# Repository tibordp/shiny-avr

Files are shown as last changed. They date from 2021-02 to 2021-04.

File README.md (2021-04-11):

# Shiny AVR Programmer

USB AVR ISP programmer specifically designed for ATtiny25/45/85 and ATtiny24/44/84/241/441/841 microcontroller families in DIP packages.

Blasphemeously designed with an STM32 microcontroller instead of an another AVR.

Shiny AVR programmer provides an 16 MHz clock signal, which allows programming chips that have had their fuse bits set to require an external crystal or clock signal.

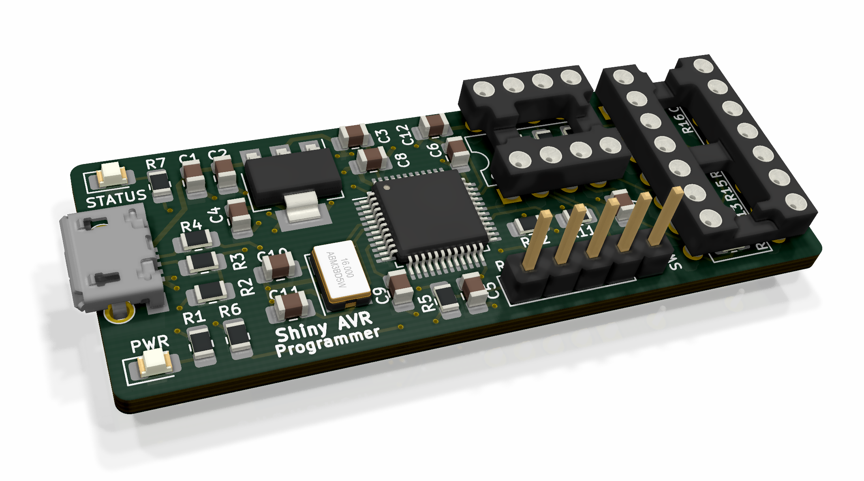
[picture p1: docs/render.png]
render


# Usage

Insert the ATtiny into the DIP socket on the programmer. Please make sure it is oriented the right way. It should also work for programming the ATtinys in circuit (unless there is circuitry wired to it that would interfere, which is likely, since ATtinys don't have dedicated programming pins), but since there is no standard ISP header on the board, you will need to provide an adapter cable.

Shiny AVR powers ATtinys with 3.3V.

## Arduino

Shiny AVR Programmer will present to the host computer as a virtual USB serial port. It can be used seamlessly from Arduino IDE by
selecting **Tools > Programmer > Arduino as ISP** and selecting the appropriate serial port.

## avrdude

Use `-c arduino` command-line parameter.

## PlatformIO

It requires some modifications to use the [avrdude.conf from ATTinyCore](https://github.com/SpenceKonde/ATTinyCore/blob/master/avr/avrdude.conf) instead of the default one bundled with PlatformIO (`chip_erase_delay` is too low in the stock one).

Example config for ATtiny85

```ini
[env:attiny85]
platform = atmelavr
board = attiny85
upload_protocol = custom
upload_flags =
    -C$PROJECT_PACKAGES_DIR/framework-arduino-avr-attiny/avrdude.conf
    -p$BOARD_MCU
    -P$UPLOAD_PORT
    -b$UPLOAD_SPEED
    -carduino
upload_command = avrdude $UPLOAD_FLAGS -U flash:w:$SOURCE:i

upload_port = <your serial port device here>
upload_speed = 19200
board_build.f_cpu = 16000000L
board_fuses.lfuse = 0xD1
board_fuses.hfuse = 0xDF
board_fuses.efuse = 0xFF
```

Example config for ATtiny84

```ini
[env:attiny84]
platform = atmelavr
board = attiny84
upload_protocol = custom
upload_flags =
    -C$PROJECT_PACKAGES_DIR/framework-arduino-avr-attiny/avrdude.conf
    -p$BOARD_MCU
    -P$UPLOAD_PORT
    -b$UPLOAD_SPEED
    -carduino
upload_command = avrdude $UPLOAD_FLAGS -U flash:w:$SOURCE:i

upload_port = <your serial port device here>
upload_speed = 19200
board_build.f_cpu = 8000000L
board_fuses.lfuse = 0x62
board_fuses.hfuse = 0xDF
board_fuses.efuse = 0xFF
```

# Hardware

The schematic and PCB layout are in the [kicad](./kicad) folder.

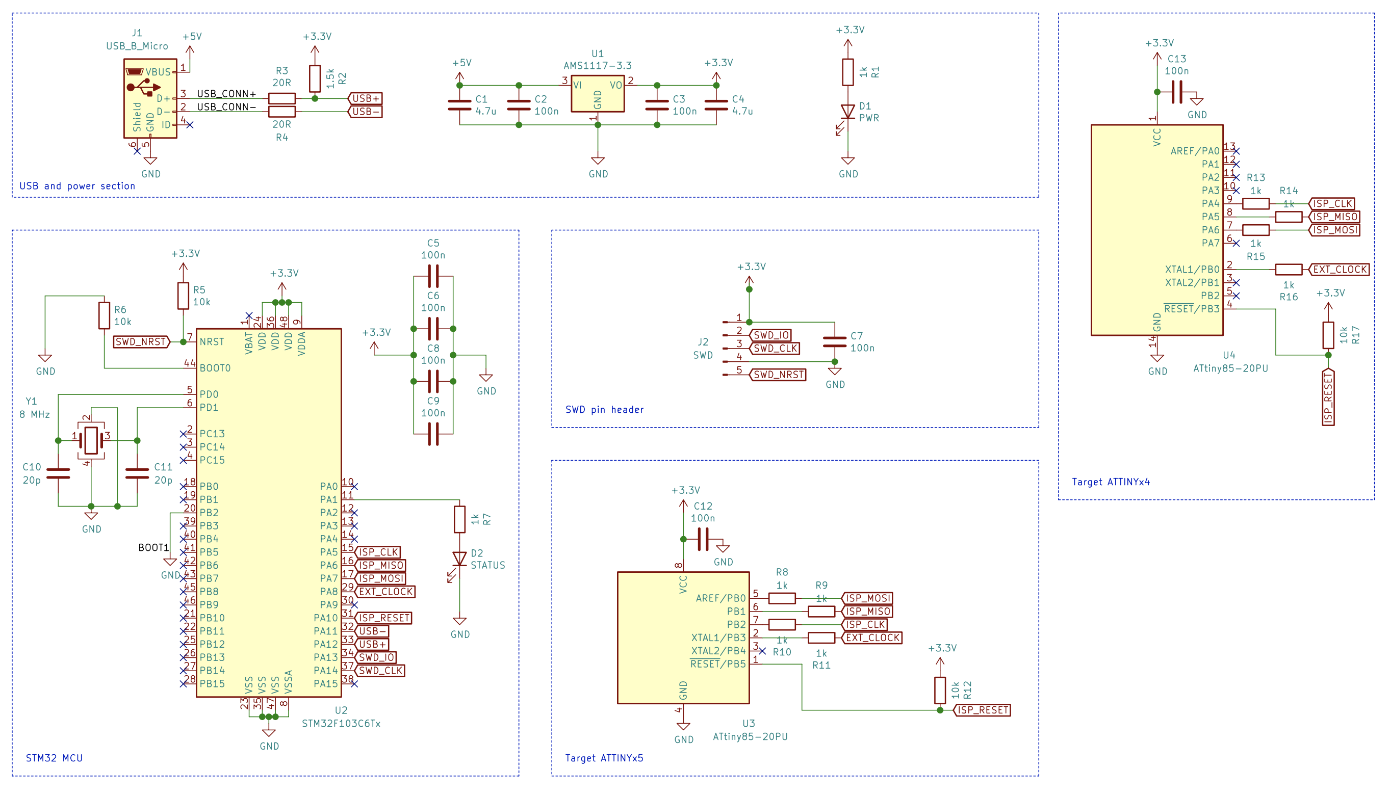
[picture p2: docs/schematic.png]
schematic

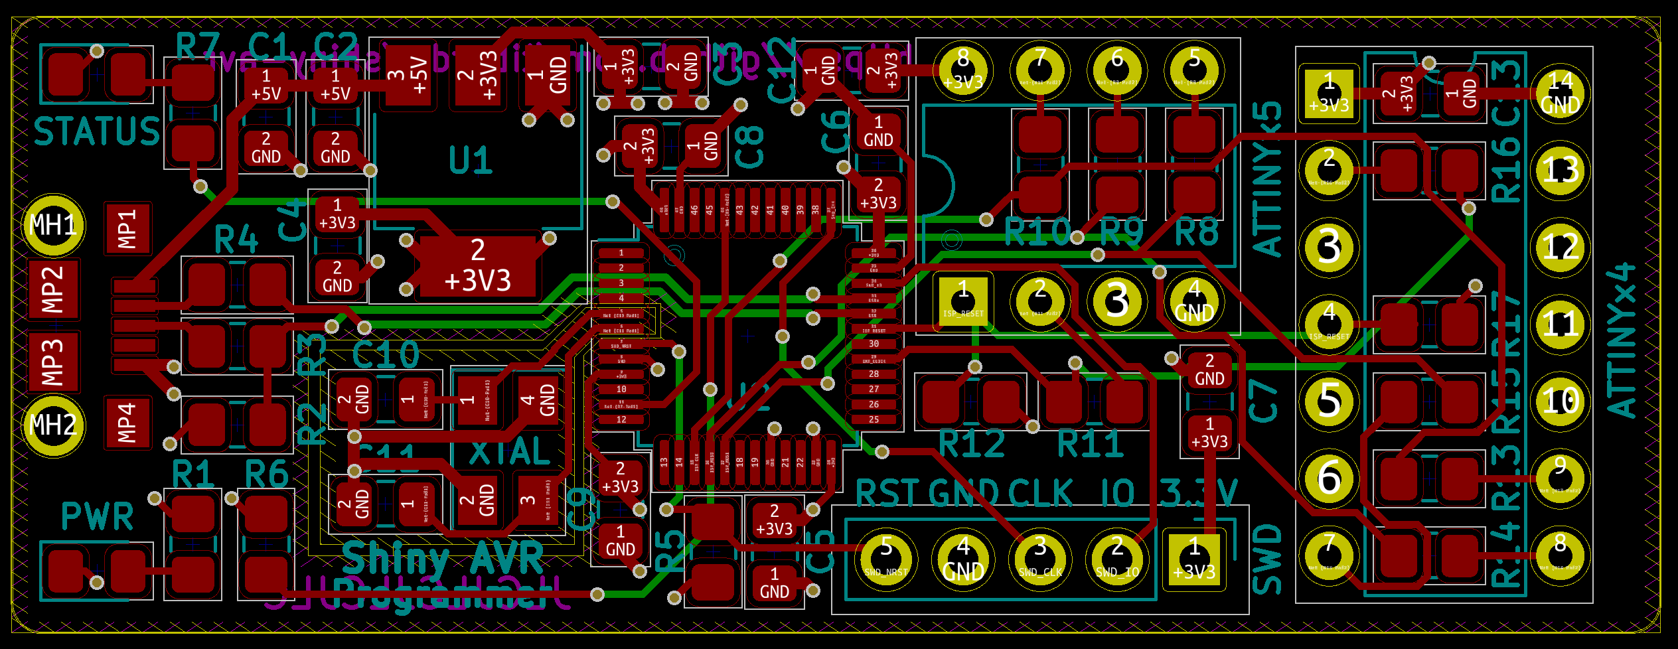
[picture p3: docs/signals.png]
signals


# Firmware

Firmware is based on [ArduinoISP](https://github.com/arduino/arduino-examples/blob/main/examples/11.ArduinoISP/ArduinoISP/ArduinoISP.ino) with the 
appropriate modifications for the specifics of hardware (LEDs, SPI parameters, ...) and it adds the capability to provide external clock to be able
to program ATtinys that have had their fuses set to rely on external clock or crystal.

# Roadmap

- High voltage programming support for chips `RSTDISBL` or debugWIRE fuse bits set  
- Managed power supply or a PTC to prevent damaging the chips 
  that are inserted upside down in the socket.

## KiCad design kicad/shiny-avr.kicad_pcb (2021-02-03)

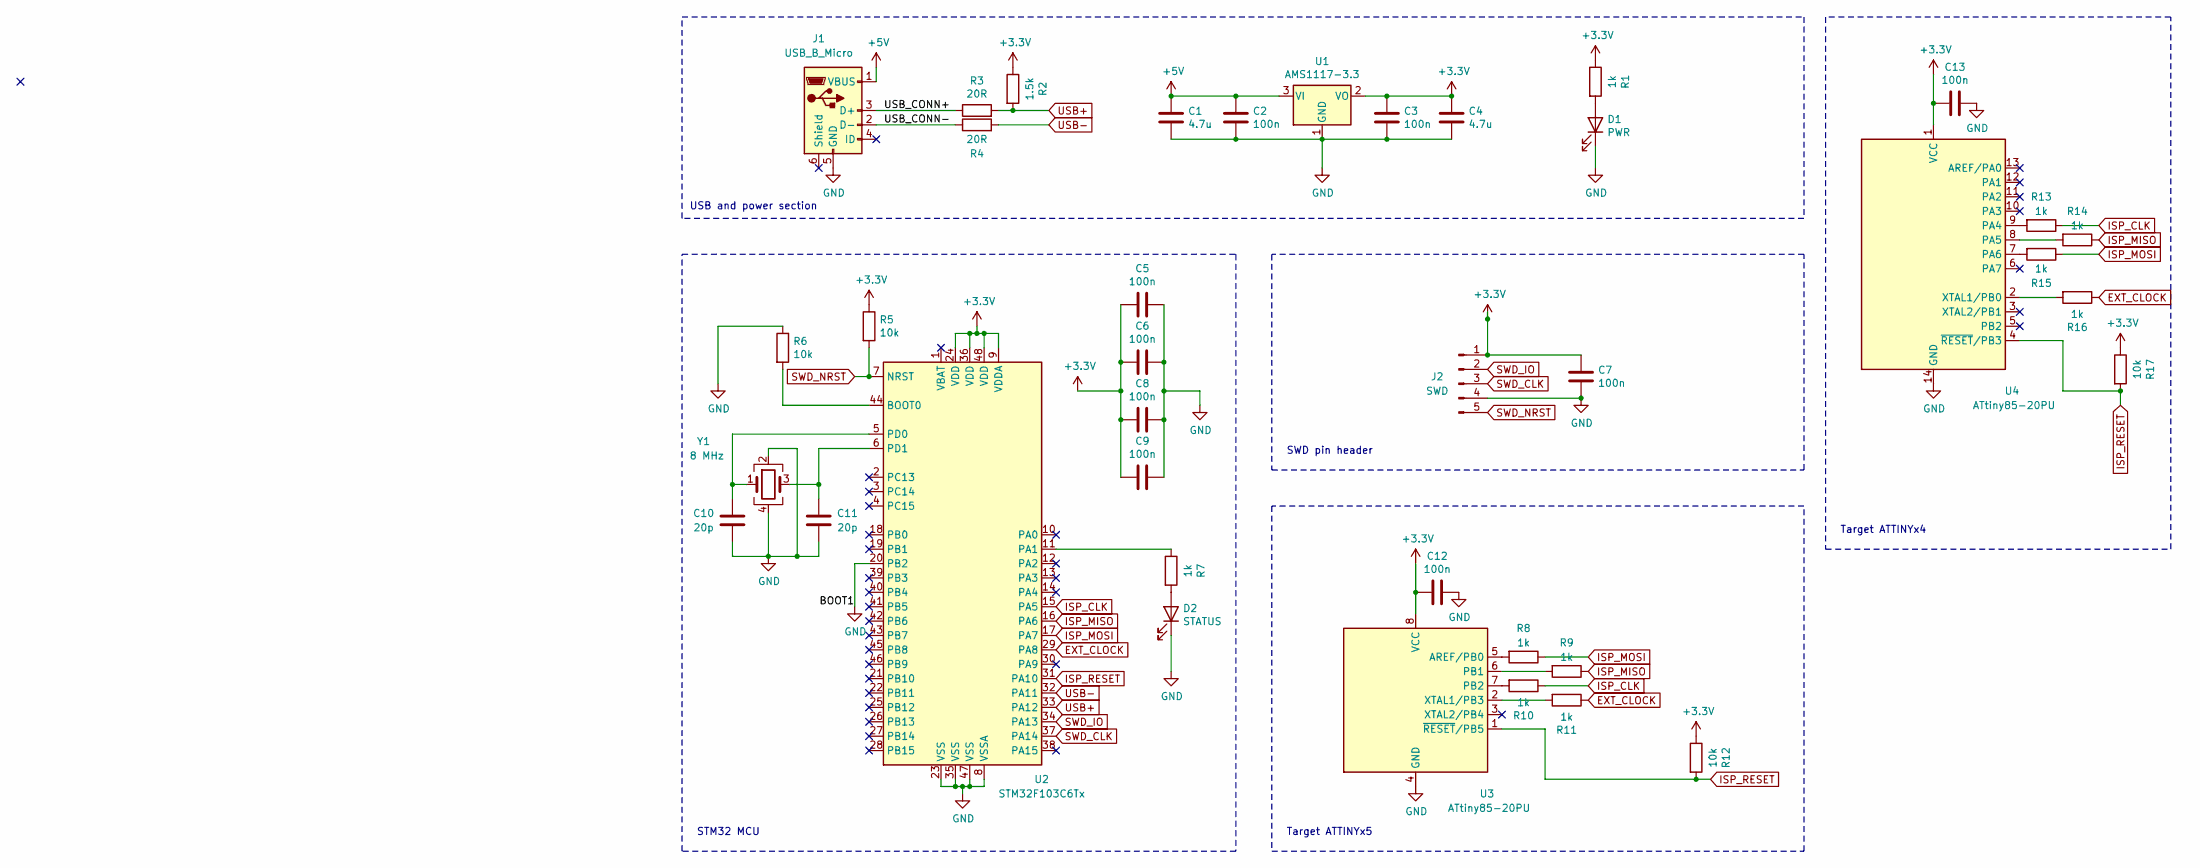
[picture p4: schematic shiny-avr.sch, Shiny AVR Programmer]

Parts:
C1, C4: 4.7u; C_0805_2012Metric_Pad1.18x1.45mm_HandSolder
C2, C3, C5, C6, C7, C8, C9, C12, C13: 100n; C_0805_2012Metric_Pad1.18x1.45mm_HandSolder
C10, C11: 20p; C_0805_2012Metric_Pad1.18x1.45mm_HandSolder
D1: PWR; LED_0805_2012Metric_Pad1.15x1.40mm_HandSolder
D2: STATUS; LED_0805_2012Metric_Pad1.15x1.40mm_HandSolder
J1: USB_B_Micro; 101181930001LF
J2: SWD; PinHeader_1x05_P2.54mm_Vertical
R1, R7, R8, R9, R10, R11, R13, R14, R15, R16: 1k; R_0805_2012Metric_Pad1.20x1.40mm_HandSolder
R2: 1.5k; R_0805_2012Metric_Pad1.20x1.40mm_HandSolder
R3, R4: 20R; R_0805_2012Metric_Pad1.20x1.40mm_HandSolder
R5, R6, R12, R17: 10k; R_0805_2012Metric_Pad1.20x1.40mm_HandSolder
U1: AMS1117-3.3; SOT-223-3_TabPin2
U2: STM32F103C6Tx; LQFP-48_7x7mm_P0.5mm
U3: ATtiny85-20PU; DIP-8_W7.62mm
U4: ATtiny85-20PU; DIP-14_W7.62mm
Y1: 8 MHz; Crystal_SMD_5032-4Pin_5.0x3.2mm

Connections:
+3V3: C3.1, C4.1, C5.2, C6.2, C7.1, C8.2, C9.2, C12.2, C13.2, J2.1, R1.1, R2.1, R5.1, R12.1, R17.1, U1.2 (VO), U2.9 (VDDA), U2.24 (VDD), U2.36 (VDD), U2.48 (VDD), U3.8 (VCC), U4.1 (VCC)
+5V: C1.1, C2.1, J1.1 (VBUS), U1.3 (VI)
/USB_CONN+: J1.3 (D+), R3.1
/USB_CONN-: J1.2 (D-), R4.1
EXT_CLOCK: R11.1, R16.1, U2.29 (PA8)
GND: C1.2, C2.2, C3.2, C4.2, C5.1, C6.1, C7.2, C8.1, C9.1, C10.2, C11.2, C12.1, C13.1, D1.1 (K), D2.1 (K), J1.5 (GND), J2.4, R6.1, U1.1 (GND), U2.8 (VSSA), U2.20 (PB2), U2.23 (VSS), U2.35 (VSS), U2.47 (VSS), U3.4 (GND), U4.14 (GND), Y1.2, Y1.4
ISP_CLK: R10.1, R13.1, U2.15 (PA5)
ISP_MISO: R9.1, R14.1, U2.16 (PA6)
ISP_MOSI: R8.1, R15.1, U2.17 (PA7)
ISP_RESET: R12.2, R17.2, U2.31 (PA10), U3.1 (~RESET~/PB5), U4.4 (~RESET~/PB3)
unnamed: C10.1, U2.5 (PD0), Y1.1
unnamed: C11.1, U2.6 (PD1), Y1.3
unnamed: D1.2 (A), R1.2
unnamed: D2.2 (A), R7.2
unnamed: R6.2, U2.44 (BOOT0)
unnamed: R7.1, U2.11 (PA1)
unnamed: R8.2, U3.5 (AREF/PB0)
unnamed: R9.2, U3.6 (PB1)
unnamed: R10.2, U3.7 (PB2)
unnamed: R11.2, U3.2 (XTAL1/PB3)
unnamed: R13.2, U4.9 (PA4)
unnamed: R14.2, U4.8 (PA5)
unnamed: R15.2, U4.7 (PA6)
unnamed: R16.2, U4.2 (XTAL1/PB0)
SWD_CLK: J2.3, U2.37 (PA14)
SWD_IO: J2.2, U2.34 (PA13)
SWD_NRST: J2.5, R5.2, U2.7 (NRST)
USB+: R2.2, R3.2, U2.33 (PA12)
USB-: R4.2, U2.32 (PA11)

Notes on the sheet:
USB and power section
STM32 MCU
Target ATTINYx5
SWD pin header
Target ATTINYx4

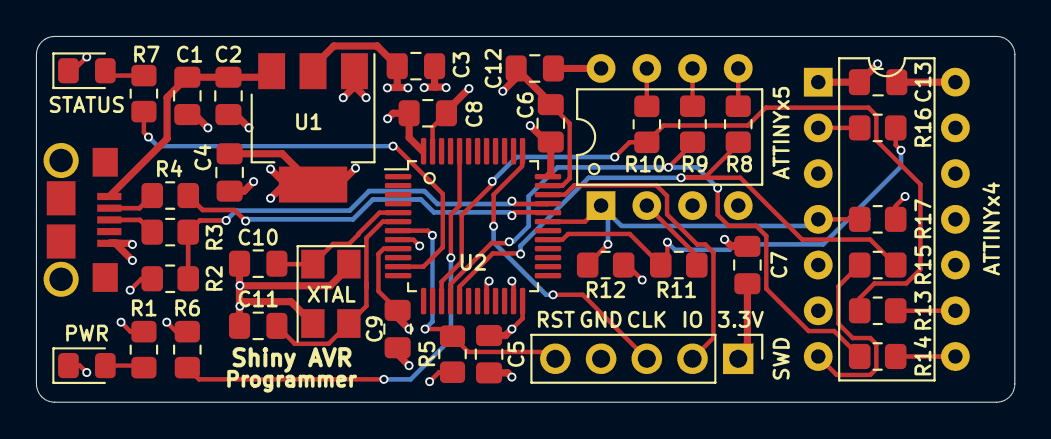
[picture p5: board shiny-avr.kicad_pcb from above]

Board: 4 copper layers, 54.4 x 20.3 mm, 39 parts (0 on the bottom side), 29 nets.

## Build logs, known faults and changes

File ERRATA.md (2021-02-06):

# Rev 1

- C1 and C2 should are swapped in board layout
- ISP MOSI is wired to pin 6 instead of pin 7 on the DIP14 socket (ATtinyX4)

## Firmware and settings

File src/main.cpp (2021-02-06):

// Shiny AVR Programmer
//
// Based on ArduinoISP, original copyright (c) 2008-2011 Randall Bohn
// https://github.com/arduino/arduino-examples/blob/main/examples/11.ArduinoISP/ArduinoISP/ArduinoISP.ino

#include "Arduino.h"

// STM32 has hardware ISP which is way too fast for most AVR chips
// that's why a bitbanged implementation is used instead.
#define SPI_CLOCK (1000000 / 6)

// Configure which pins to use:
#define RESET PA10
#define LED_STATUS PA1

#define PIN_MOSI PA7
#define PIN_MISO PA6
#define PIN_SCK PA5
#define PIN_EXT_CLOCK PA8

#define BAUDRATE 19200

#define HWVER 2
#define SWMAJ 1
#define SWMIN 18

// STK Definitions
#define STK_OK 0x10
#define STK_FAILED 0x11
#define STK_UNKNOWN 0x12
#define STK_INSYNC 0x14
#define STK_NOSYNC 0x15
#define CRC_EOP 0x20 // ok it is a space...

void pulse(int pin, int times);
void avrisp();

#define SPI_MODE0 0x00

class SPISettings {
public:
  // clock is in Hz
  SPISettings(uint32_t clock, uint8_t bitOrder, uint8_t dataMode)
      : clock(clock) {
    (void)bitOrder;
    (void)dataMode;
  };

private:
  uint32_t clock;

  friend class BitBangedSPI;
};

class BitBangedSPI {
public:
  void begin() {
    digitalWrite(PIN_SCK, LOW);
    digitalWrite(PIN_MOSI, LOW);
    pinMode(PIN_SCK, OUTPUT);
    pinMode(PIN_MOSI, OUTPUT);
    pinMode(PIN_MISO, INPUT);
  }

  void beginTransaction(SPISettings settings) {
    pulseWidth = (500000 + settings.clock - 1) / settings.clock;
    if (pulseWidth == 0)
      pulseWidth = 1;
  }

  void end() {}

  uint8_t transfer(uint8_t b) {
    for (unsigned int i = 0; i < 8; ++i) {
      digitalWrite(PIN_MOSI, (b & 0x80) ? HIGH : LOW);
      digitalWrite(PIN_SCK, HIGH);
      delayMicroseconds(pulseWidth);
      b = (b << 1) | digitalRead(PIN_MISO);
      digitalWrite(PIN_SCK, LOW); // slow pulse
      delayMicroseconds(pulseWidth);
    }
    return b;
  }

private:
  unsigned long pulseWidth; // in microseconds
};

static BitBangedSPI SPI;

void setup() {
  Serial.begin(BAUDRATE);

  pinMode(LED_STATUS, OUTPUT);
  pulse(LED_STATUS, 2);
}

int error = 0;
int pmode = 0;
// address for reading and writing, set by 'U' command
unsigned int here;
uint8_t buff[256]; // global block storage

#define beget16(addr) (*addr * 256 + *(addr + 1))
typedef struct param {
  uint8_t devicecode;
  uint8_t revision;
  uint8_t progtype;
  uint8_t parmode;
  uint8_t polling;
  uint8_t selftimed;
  uint8_t lockbytes;
  uint8_t fusebytes;
  uint8_t flashpoll;
  uint16_t eeprompoll;
  uint16_t pagesize;
  uint16_t eepromsize;
  uint32_t flashsize;
} parameter;

parameter param;

static bool rst_active_high;

void reset_target(bool reset) {
  digitalWrite(RESET,
               ((reset && rst_active_high) || (!reset && !rst_active_high))
                   ? HIGH
                   : LOW);
}

void loop(void) {
  if (error) {
    digitalWrite(LED_STATUS, (millis() % 500) < 250);
  } else if (pmode) {
    digitalWrite(LED_STATUS, HIGH);
  } else {
    digitalWrite(LED_STATUS, LOW);
  }

  if (Serial.available()) {
    avrisp();
  }
}

uint8_t getch() {
  while (!Serial.available())
    ;
  return Serial.read();
}
void fill(int n) {
  for (int x = 0; x < n; x++) {
    buff[x] = getch();
  }
}

#define PTIME 30
void pulse(int pin, int times) {
  do {
    digitalWrite(pin, HIGH);
    delay(PTIME);
    digitalWrite(pin, LOW);
    delay(PTIME);
  } while (times--);
}

uint8_t spi_transaction(uint8_t a, uint8_t b, uint8_t c, uint8_t d) {
  SPI.transfer(a);
  SPI.transfer(b);
  SPI.transfer(c);
  return SPI.transfer(d);
}

void empty_reply() {
  if (CRC_EOP == getch()) {
    Serial.print((char)STK_INSYNC);
    Serial.print((char)STK_OK);
  } else {
    error++;
    Serial.print((char)STK_NOSYNC);
  }
}

void breply(uint8_t b) {
  if (CRC_EOP == getch()) {
    Serial.print((char)STK_INSYNC);
    Serial.print((char)b);
    Serial.print((char)STK_OK);
  } else {
    error++;
    Serial.print((char)STK_NOSYNC);
  }
}

void get_version(uint8_t c) {
  switch (c) {
  case 0x80:
    breply(HWVER);
    break;
  case 0x81:
    breply(SWMAJ);
    break;
  case 0x82:
    breply(SWMIN);
    break;
  case 0x93:
    breply('S'); // serial programmer
    break;
  default:
    breply(0);
  }
}

void set_parameters() {
  // call this after reading parameter packet into buff[]
  param.devicecode = buff[0];
  param.revision = buff[1];
  param.progtype = buff[2];
  param.parmode = buff[3];
  param.polling = buff[4];
  param.selftimed = buff[5];
  param.lockbytes = buff[6];
  param.fusebytes = buff[7];
  param.flashpoll = buff[8];
  // ignore buff[9] (= buff[8])
  // following are 16 bits (big endian)
  param.eeprompoll = beget16(&buff[10]);
  param.pagesize = beget16(&buff[12]);
  param.eepromsize = beget16(&buff[14]);

  // 32 bits flashsize (big endian)
  param.flashsize = buff[16] * 0x01000000 + buff[17] * 0x00010000 +
                    buff[18] * 0x00000100 + buff[19];

  // AVR devices have active low reset, AT89Sx are active high
  rst_active_high = (param.devicecode >= 0xe0);
}

void start_pmode() {

  // Reset target before driving PIN_SCK or PIN_MOSI

  // SPI.begin() will configure SS as output, so SPI master mode is selected.
  // We have defined RESET as pin 10, which for many Arduinos is not the SS pin.
  // So we have to configure RESET as output here,
  // (reset_target() first sets the correct level)
  reset_target(true);

  // Start the external clock at 16 MHz for ATtinys that require external clock or crystal
  pinMode(PIN_EXT_CLOCK, OUTPUT);
  analogWriteResolution(2);
  analogWriteFrequency(16000000);
  analogWrite(PIN_EXT_CLOCK, 1);
  pinMode(RESET, OUTPUT);
  
  SPI.begin();
  SPI.beginTransaction(SPISettings(SPI_CLOCK, MSBFIRST, SPI_MODE0));

  // See AVR datasheets, chapter "Serial_PRG Programming Algorithm":

  // Pulse RESET after PIN_SCK is low:
  digitalWrite(PIN_SCK, LOW);
  delay(20); // discharge PIN_SCK, value arbitrarily chosen
  reset_target(false);
  // Pulse must be minimum 2 target CPU clock cycles so 100 usec is ok for CPU
  // speeds above 20 KHz
  delayMicroseconds(100);
  reset_target(true);

  // Send the enable programming command:
  delay(50); // datasheet: must be > 20 msec
  spi_transaction(0xAC, 0x53, 0x00, 0x00);
  pmode = 1;
}

void end_pmode() {
  SPI.end();
  // We're about to take the target out of reset so configure SPI pins as input
  pinMode(PIN_MOSI, INPUT);
  pinMode(PIN_SCK, INPUT);
  pinMode(PIN_EXT_CLOCK, INPUT);

  reset_target(false);
  pinMode(RESET, INPUT);
  pmode = 0;
}

void universal() {
  uint8_t ch;

  fill(4);
  ch = spi_transaction(buff[0], buff[1], buff[2], buff[3]);
  breply(ch);
}

void flash(uint8_t hilo, unsigned int addr, uint8_t data) {
  spi_transaction(0x40 + 8 * hilo, addr >> 8 & 0xFF, addr & 0xFF, data);
}
void commit(unsigned int addr) {
  spi_transaction(0x4C, (addr >> 8) & 0xFF, addr & 0xFF, 0);

  // This delay is important, otherwise we get verification errors with avrdude
  delay(PTIME);
}

unsigned int current_page() {
  if (param.pagesize == 32) {
    return here & 0xFFFFFFF0;
  }
  if (param.pagesize == 64) {
    return here & 0xFFFFFFE0;
  }
  if (param.pagesize == 128) {
    return here & 0xFFFFFFC0;
  }
  if (param.pagesize == 256) {
    return here & 0xFFFFFF80;
  }
  return here;
}

uint8_t write_flash_pages(int length);

void write_flash(int length) {
  fill(length);
  if (CRC_EOP == getch()) {
    Serial.print((char)STK_INSYNC);
    Serial.print((char)write_flash_pages(length));
  } else {
    error++;
    Serial.print((char)STK_NOSYNC);
  }
}

uint8_t write_flash_pages(int length) {
  int x = 0;
  unsigned int page = current_page();
  while (x < length) {
    if (page != current_page()) {
      commit(page);
      page = current_page();
    }
    flash(LOW, here, buff[x++]);
    flash(HIGH, here, buff[x++]);
    here++;
  }

  commit(page);

  return STK_OK;
}

uint8_t write_eeprom_chunk(unsigned int start, unsigned int length);

#define EECHUNK (32)

uint8_t write_eeprom(unsigned int length) {
  // here is a word address, get the byte address
  unsigned int start = here * 2;
  unsigned int remaining = length;
  if (length > param.eepromsize) {
    error++;
    return STK_FAILED;
  }
  while (remaining > EECHUNK) {
    write_eeprom_chunk(start, EECHUNK);
    start += EECHUNK;
    remaining -= EECHUNK;
  }
  write_eeprom_chunk(start, remaining);
  return STK_OK;
}
// write (length) bytes, (start) is a byte address
uint8_t write_eeprom_chunk(unsigned int start, unsigned int length) {
  // this writes byte-by-byte, page writing may be faster (4 bytes at a time)
  fill(length);
  for (unsigned int x = 0; x < length; x++) {
    unsigned int addr = start + x;
    spi_transaction(0xC0, (addr >> 8) & 0xFF, addr & 0xFF, buff[x]);
    delay(45);
  }
  return STK_OK;
}

void program_page() {
  char result = (char)STK_FAILED;
  unsigned int length = 256 * getch();
  length += getch();
  char memtype = getch();
  // flash memory @here, (length) bytes
  if (memtype == 'F') {
    write_flash(length);
    return;
  }
  if (memtype == 'E') {
    result = (char)write_eeprom(length);
    if (CRC_EOP == getch()) {
      Serial.print((char)STK_INSYNC);
      Serial.print(result);
    } else {
      error++;
      Serial.print((char)STK_NOSYNC);
    }
    return;
  }
  Serial.print((char)STK_FAILED);
  return;
}

uint8_t flash_read(uint8_t hilo, unsigned int addr) {
  return spi_transaction(0x20 + hilo * 8, (addr >> 8) & 0xFF, addr & 0xFF, 0);
}

char flash_read_page(int length) {
  for (int x = 0; x < length; x += 2) {
    uint8_t low = flash_read(LOW, here);
    Serial.print((char)low);
    uint8_t high = flash_read(HIGH, here);
    Serial.print((char)high);
    here++;
  }
  return STK_OK;
}

char eeprom_read_page(int length) {
  // here again we have a word address
  int start = here * 2;
  for (int x = 0; x < length; x++) {
    int addr = start + x;
    uint8_t ee = spi_transaction(0xA0, (addr >> 8) & 0xFF, addr & 0xFF, 0xFF);
    Serial.print((char)ee);
  }
  return STK_OK;
}

void read_page() {
  char result = (char)STK_FAILED;
  int length = 256 * getch();
  length += getch();
  char memtype = getch();
  if (CRC_EOP != getch()) {
    error++;
    Serial.print((char)STK_NOSYNC);
    return;
  }
  Serial.print((char)STK_INSYNC);
  if (memtype == 'F')
    result = flash_read_page(length);
  if (memtype == 'E')
    result = eeprom_read_page(length);
  Serial.print(result);
}

void read_signature() {
  if (CRC_EOP != getch()) {
    error++;
    Serial.print((char)STK_NOSYNC);
    return;
  }
  Serial.print((char)STK_INSYNC);
  uint8_t high = spi_transaction(0x30, 0x00, 0x00, 0x00);
  Serial.print((char)high);
  uint8_t middle = spi_transaction(0x30, 0x00, 0x01, 0x00);
  Serial.print((char)middle);
  uint8_t low = spi_transaction(0x30, 0x00, 0x02, 0x00);
  Serial.print((char)low);
  Serial.print((char)STK_OK);
}
//////////////////////////////////////////
//////////////////////////////////////////

////////////////////////////////////
////////////////////////////////////
void avrisp() {
  uint8_t ch = getch();
  switch (ch) {
  case '0': // signon
    error = 0;
    empty_reply();
    break;
  case '1':
    if (getch() == CRC_EOP) {
      Serial.print((char)STK_INSYNC);
      Serial.print("AVR ISP");
      Serial.print((char)STK_OK);
    } else {
      error++;
      Serial.print((char)STK_NOSYNC);
    }
    break;
  case 'A':
    get_version(getch());
    break;
  case 'B':
    fill(20);
    set_parameters();
    empty_reply();
    break;
  case 'E': // extended parameters - ignore for now
    fill(5);
    empty_reply();
    break;
  case 'P':
    if (!pmode)
      start_pmode();
    empty_reply();
    break;
  case 'U': // set address (word)
    here = getch();
    here += 256 * getch();
    empty_reply();
    break;

  case 0x60: // STK_PROG_FLASH
    getch(); // low addr
    getch(); // high addr
    empty_reply();
    break;
  case 0x61: // STK_PROG_DATA
    getch(); // data
    empty_reply();
    break;

  case 0x64: // STK_PROG_PAGE
    program_page();
    break;

  case 0x74: // STK_READ_PAGE 't'
    read_page();
    break;

  case 'V': // 0x56
    universal();
    break;
  case 'Q': // 0x51
    error = 0;
    end_pmode();
    empty_reply();
    break;

  case 0x75: // STK_READ_SIGN 'u'
    read_signature();
    break;

  // expecting a command, not CRC_EOP
  // this is how we can get back in sync
  case CRC_EOP:
    error++;
    Serial.print((char)STK_NOSYNC);
    break;

  // anything else we will return STK_UNKNOWN
  default:
    error++;
    if (CRC_EOP == getch())
      Serial.print((char)STK_UNKNOWN);
    else
      Serial.print((char)STK_NOSYNC);
  }
}

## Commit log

2021-01-12 Initial commit.
    [SmolISP.kicad_pcb, SmolISP.sch]
2021-01-12 Changes after PCB review
    [SmolISP.kicad_pcb, SmolISP.sch]
2021-01-13 Relicense + rename
    [SmolISP.kicad_pcb, shiny-avr.kicad_pcb, shiny-avr.sch]
2021-02-03 ci: Add CI (#1)
    [shiny-avr.kicad_pcb]
2021-02-03 Add support for ATtiny24/44/48 (#2)
    [shiny-avr.kicad_pcb, shiny-avr.sch]
2021-02-03 Add firmware
    [shiny-avr.kicad_pcb, shiny-avr.sch]
2021-02-03 fix: Swapped pins 6 and 7 on ATtinyX4 socket (#4)
    * fix: Swapped pins 6 and 7 on ATtinyX4 socket
    * fix: images
    [shiny-avr.kicad_pcb, shiny-avr.sch]
